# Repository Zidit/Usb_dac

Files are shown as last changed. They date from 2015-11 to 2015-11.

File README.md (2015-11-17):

USB DAC
=======
Basic external sound card based on Texas Instrument's PCM2706 USB DAC. The sound card has build in headphone amplifier based on NwAvGuy's [O2](http://nwavguy.blogspot.fi/2011/08/o2-details.html) design. It also has two line outputs and optical s/pdif output. All line and headphone outputs have individual volume control on front.
The amplifier needs external power supply to work. Power supply must provide 12 V to 16 V AC and at least 200 mA of current. There is also option to skip all amplification circuitry and drive headphone output directly from PCM2706. This way you don't need external power, but you lose line outputs and volume control.

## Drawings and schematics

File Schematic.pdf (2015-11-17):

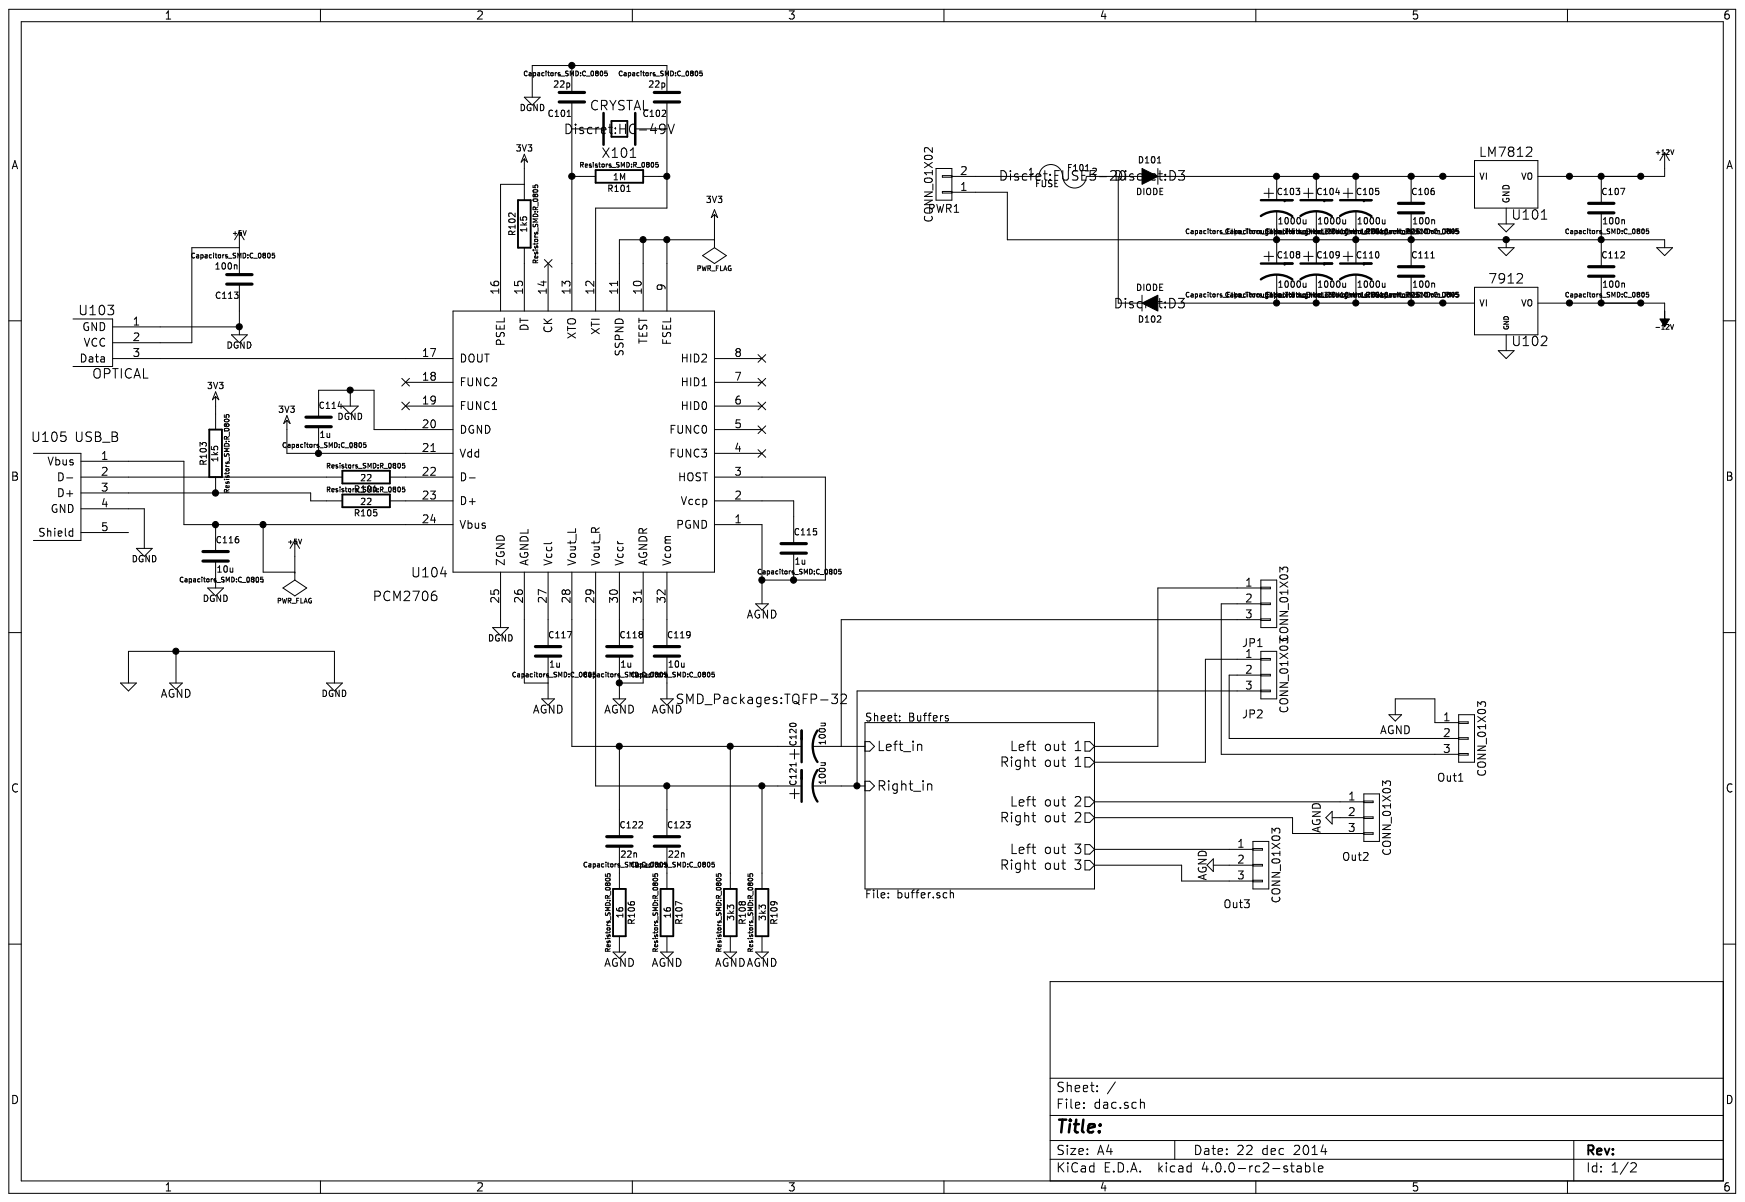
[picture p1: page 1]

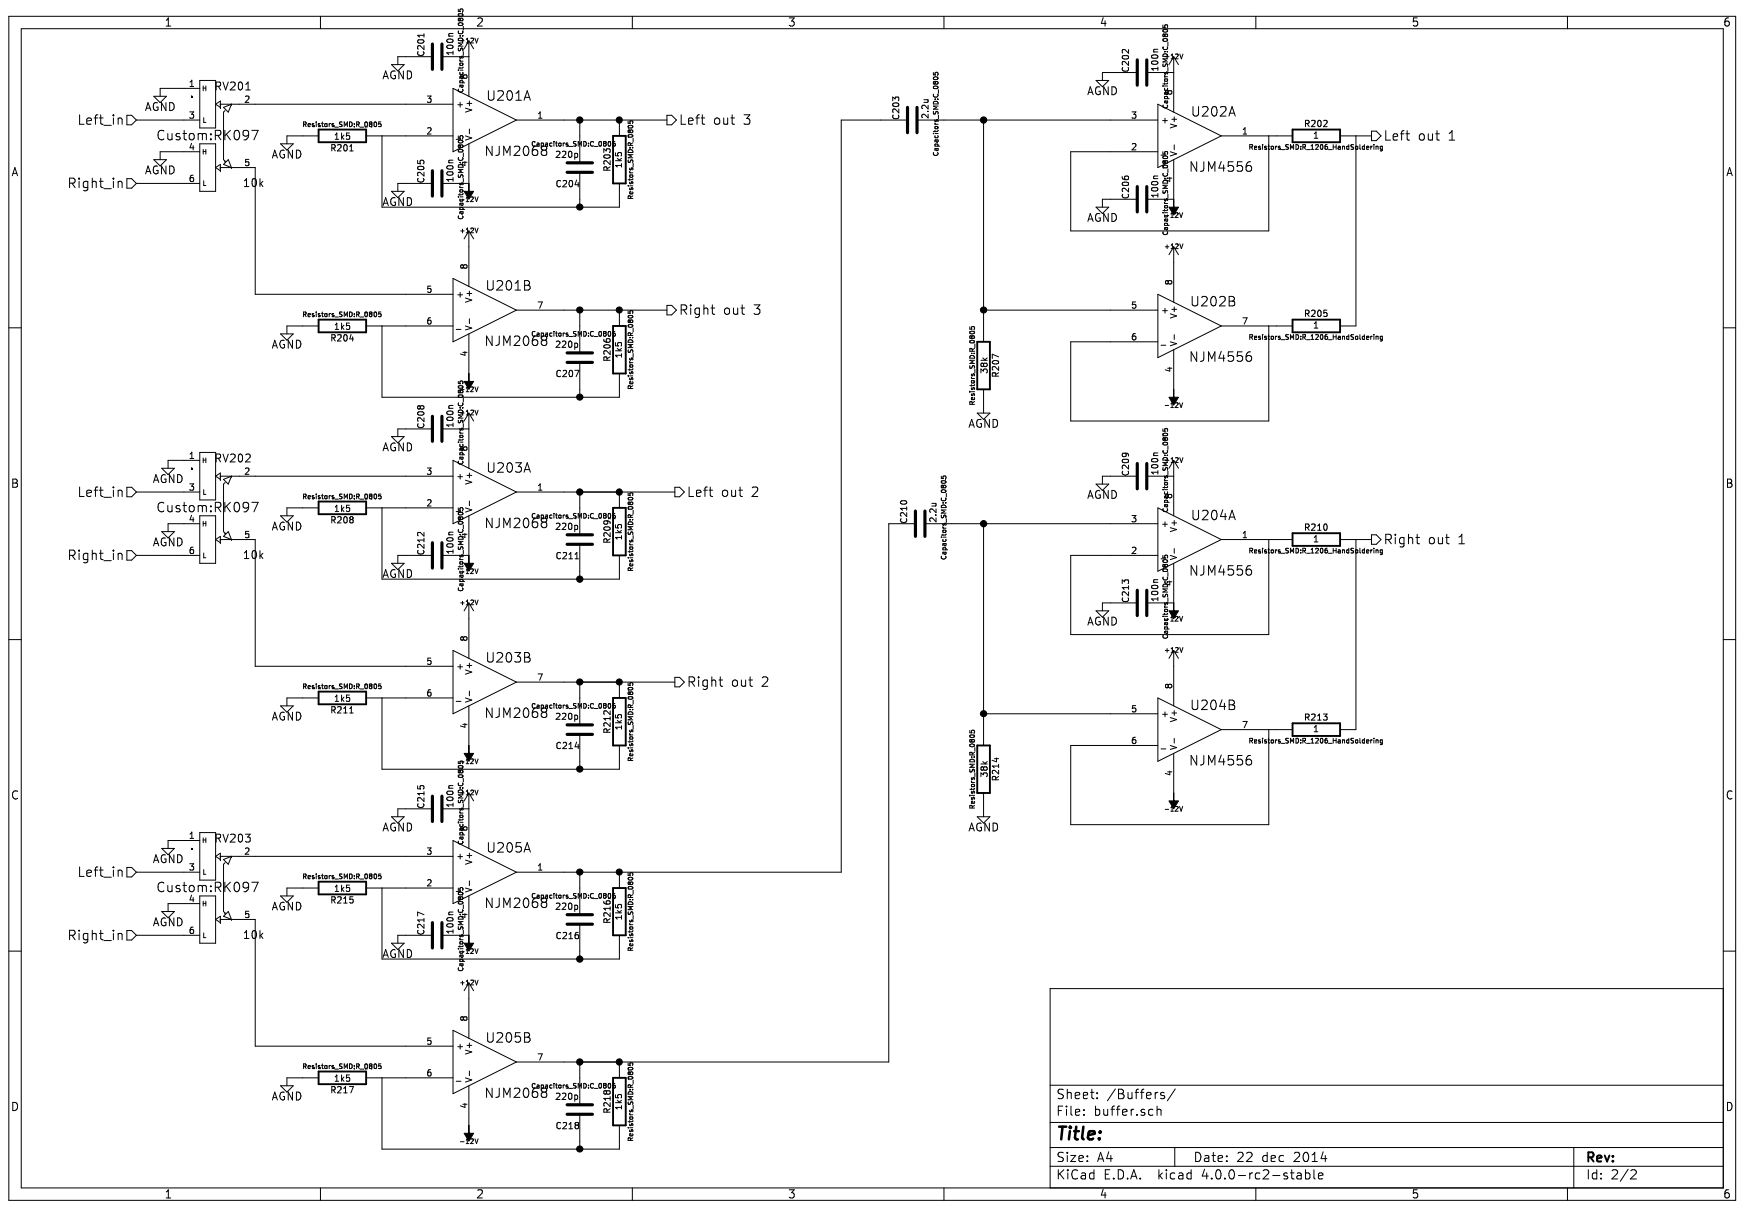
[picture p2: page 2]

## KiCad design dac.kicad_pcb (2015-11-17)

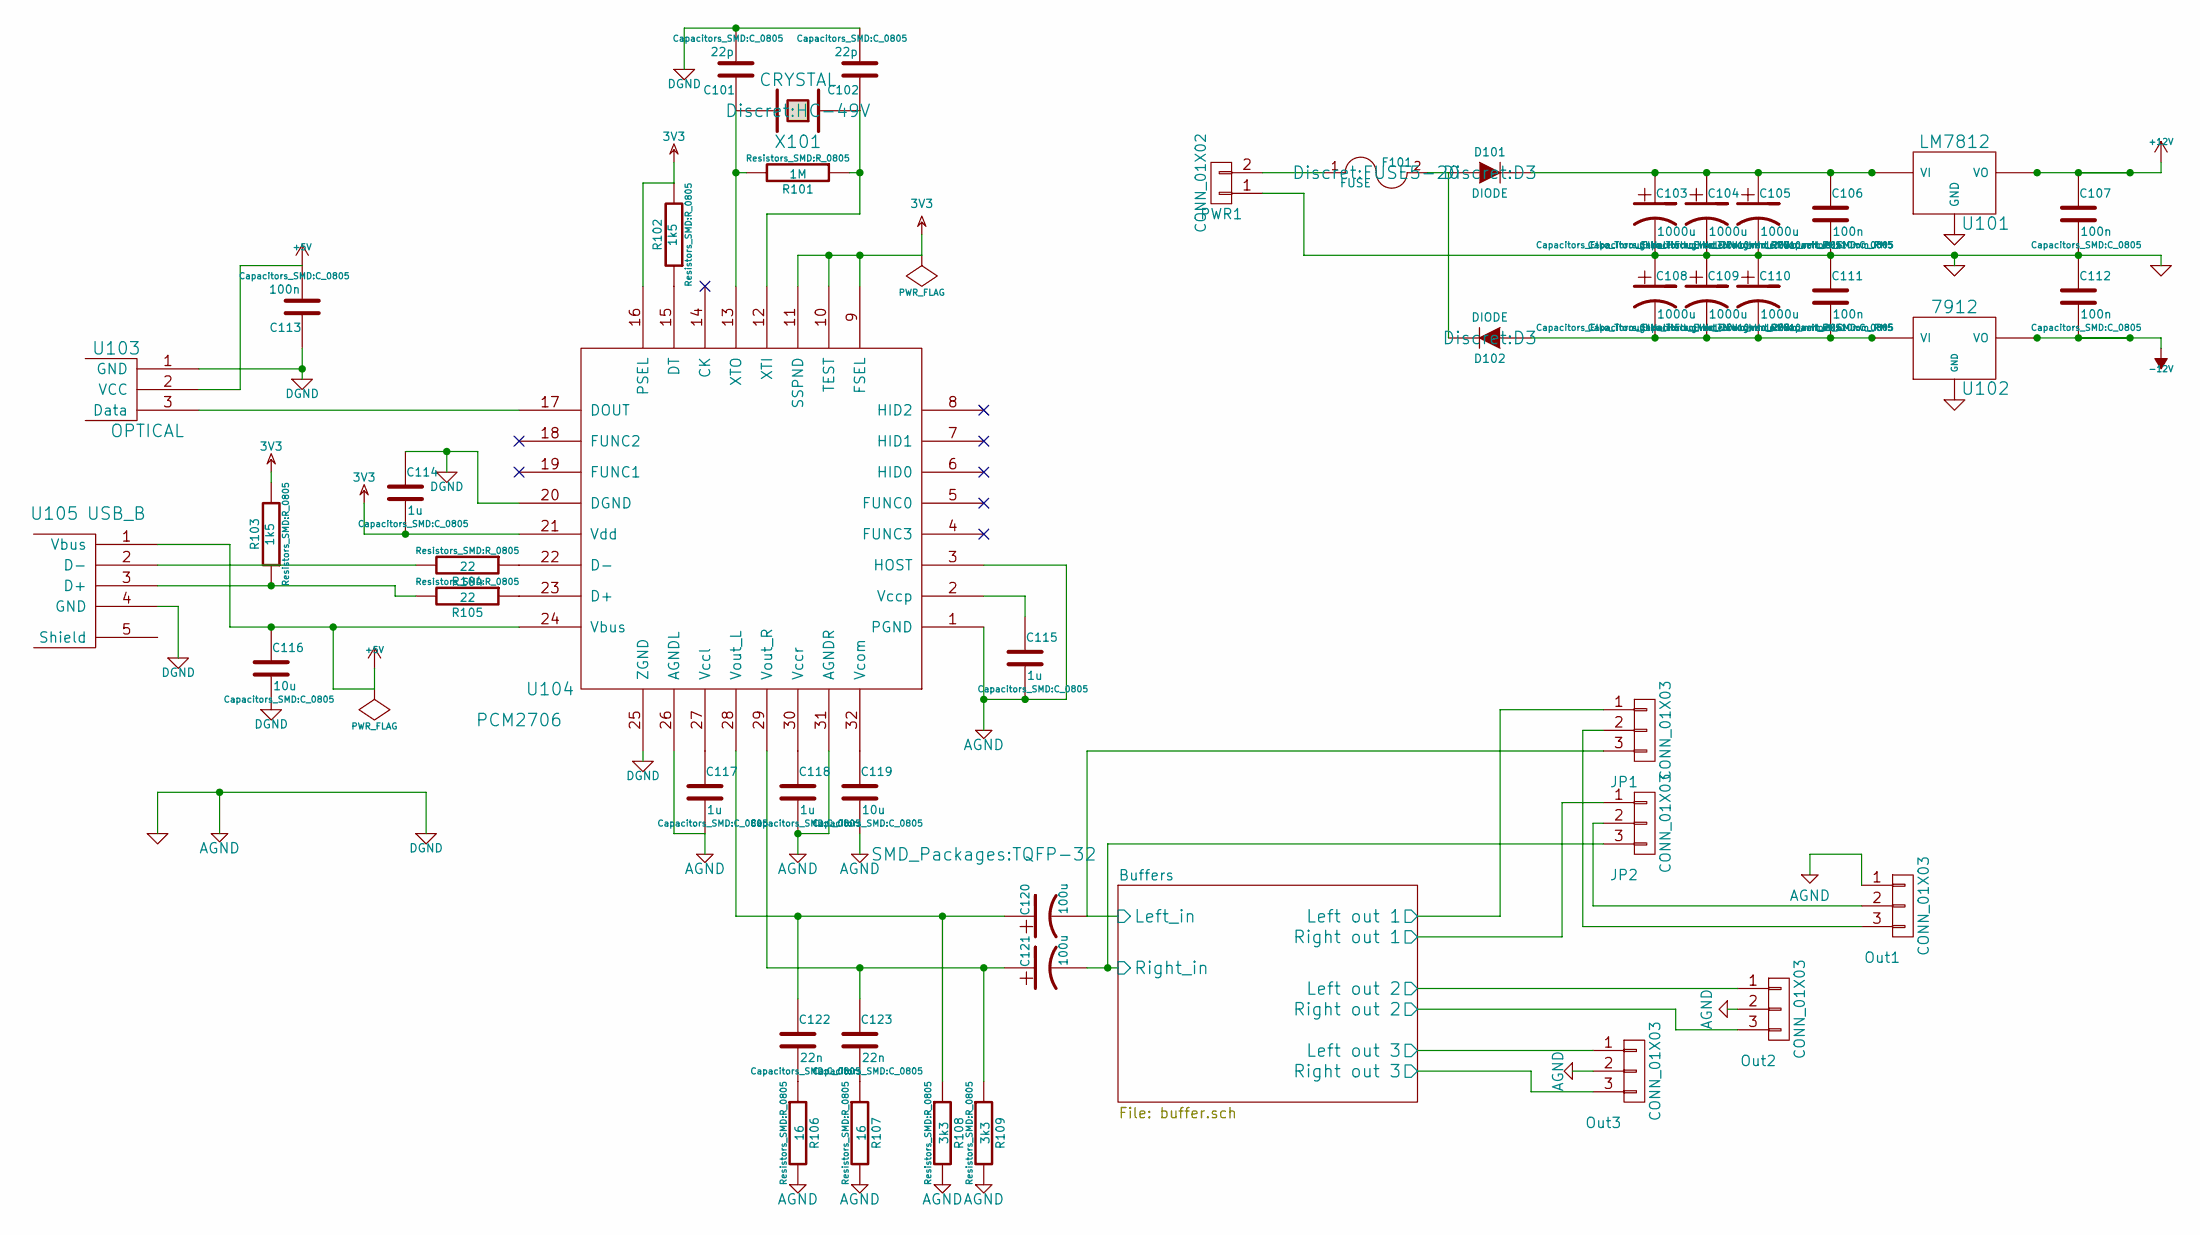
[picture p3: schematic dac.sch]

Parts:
C101, C102: 22p; C_0805
C103, C104, C105, C108, C109, C110: 1000u; Elko_vert_20x10mm_RM5
C106, C107, C111, C112, C113: 100n; C_0805
C114, C115, C117, C118: 1u; C_0805
C116, C119: 10u; C_0805
C120, C121: 100u; c_elec_6.3x5.3
C122, C123: 22n; C_0805
D101, D102: DIODE; D3
F101: FUSE; FUSE5-20
JP1, JP2: CONN_01X03; Pin_Header_Straight_1x03
Out1: CONN_01X03; SIKA
Out2, Out3: CONN_01X03; Pin_Header_Straight_1x03
PWR1: CONN_01X02; Pin_Header_Straight_1x02
R101: 1M; R_0805
R102, R103: 1k5; R_0805
R104, R105: 22; R_0805
R106, R107: 16; R_0805
R108, R109: 3k3; R_0805
U101: LM7812; TO220
U102: 7912; TO220
U103: OPTICAL; KFOX
U104: PCM2706; TQFP-32
U105: USB_B
X101: CRYSTAL; HC-49V

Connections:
3V3: C114.2, R102.2, R103.2, U104.9 (FSEL), U104.10 (TEST), U104.11 (SSPND), U104.16 (PSEL), U104.21 (Vdd)
+5V: C113.2, C116.1, U103.2 (VCC), U104.24 (Vbus), U105.1 (Vbus)
+12V: C107.1, U101.3 (VO); also elsewhere on the board
-12V: C112.2, U102.3 (VO); also elsewhere on the board
/Buffers/Left out 1: JP1.1; also elsewhere on the board
/Buffers/Left out 2: Out2.1; also elsewhere on the board
/Buffers/Left out 3: Out3.1; also elsewhere on the board
/Buffers/Left_in: C120.2, JP1.3; also elsewhere on the board
/Buffers/Right out 1: JP2.1; also elsewhere on the board
/Buffers/Right out 2: Out2.3; also elsewhere on the board
/Buffers/Right out 3: Out3.3; also elsewhere on the board
/Buffers/Right_in: C121.2, JP2.3; also elsewhere on the board
AGND: C101.2, C102.2, C103.2, C104.2, C105.2, C106.2, C107.2, C108.1, C109.1, C110.1, C111.1, C112.1, C113.1, C114.1, C115.2, C116.2, C117.2, C118.2, C119.2, Out1.1, Out2.2, Out3.2, PWR1.1, R106.2, R107.2, R108.2, R109.2, U101.2 (GND), U102.1 (GND), U103.1 (GND), U104.1 (PGND), U104.3 (HOST), U104.20 (DGND), U104.25 (ZGND), U104.26 (AGNDL), U104.31 (AGNDR), U105.4 (GND); also elsewhere on the board
unnamed: C101.1, R101.2, U104.13 (XTO), X101.2
unnamed: C102.1, R101.1, U104.12 (XTI), X101.1
unnamed: C103.1, C104.1, C105.1, C106.1, D101.2 (K), U101.1 (VI)
unnamed: C108.2, C109.2, C110.2, C111.2, D102.1 (A), U102.2 (VI)
unnamed: C115.1, U104.2 (Vccp)
unnamed: C117.1, U104.27 (Vccl)
unnamed: C118.1, U104.30 (Vccr)
unnamed: C119.1, U104.32 (Vcom)
unnamed: C120.1, C122.1, R108.1, U104.28 (Vout_L)
unnamed: C121.1, C123.1, R109.1, U104.29 (Vout_R)
unnamed: C122.2, R106.1
unnamed: C123.2, R107.1
unnamed: D101.1 (A), D102.2 (K), F101.2
unnamed: F101.1, PWR1.2
unnamed: JP1.2, Out1.3
unnamed: JP2.2, Out1.2
unnamed: R102.1, U104.15 (DT)
unnamed: R103.1, R105.2, U105.3 (D+)
unnamed: R104.1, U104.22 (D-)
unnamed: R104.2, U105.2 (D-)
unnamed: R105.1, U104.23 (D+)
unnamed: U103.3 (Data), U104.17 (DOUT)

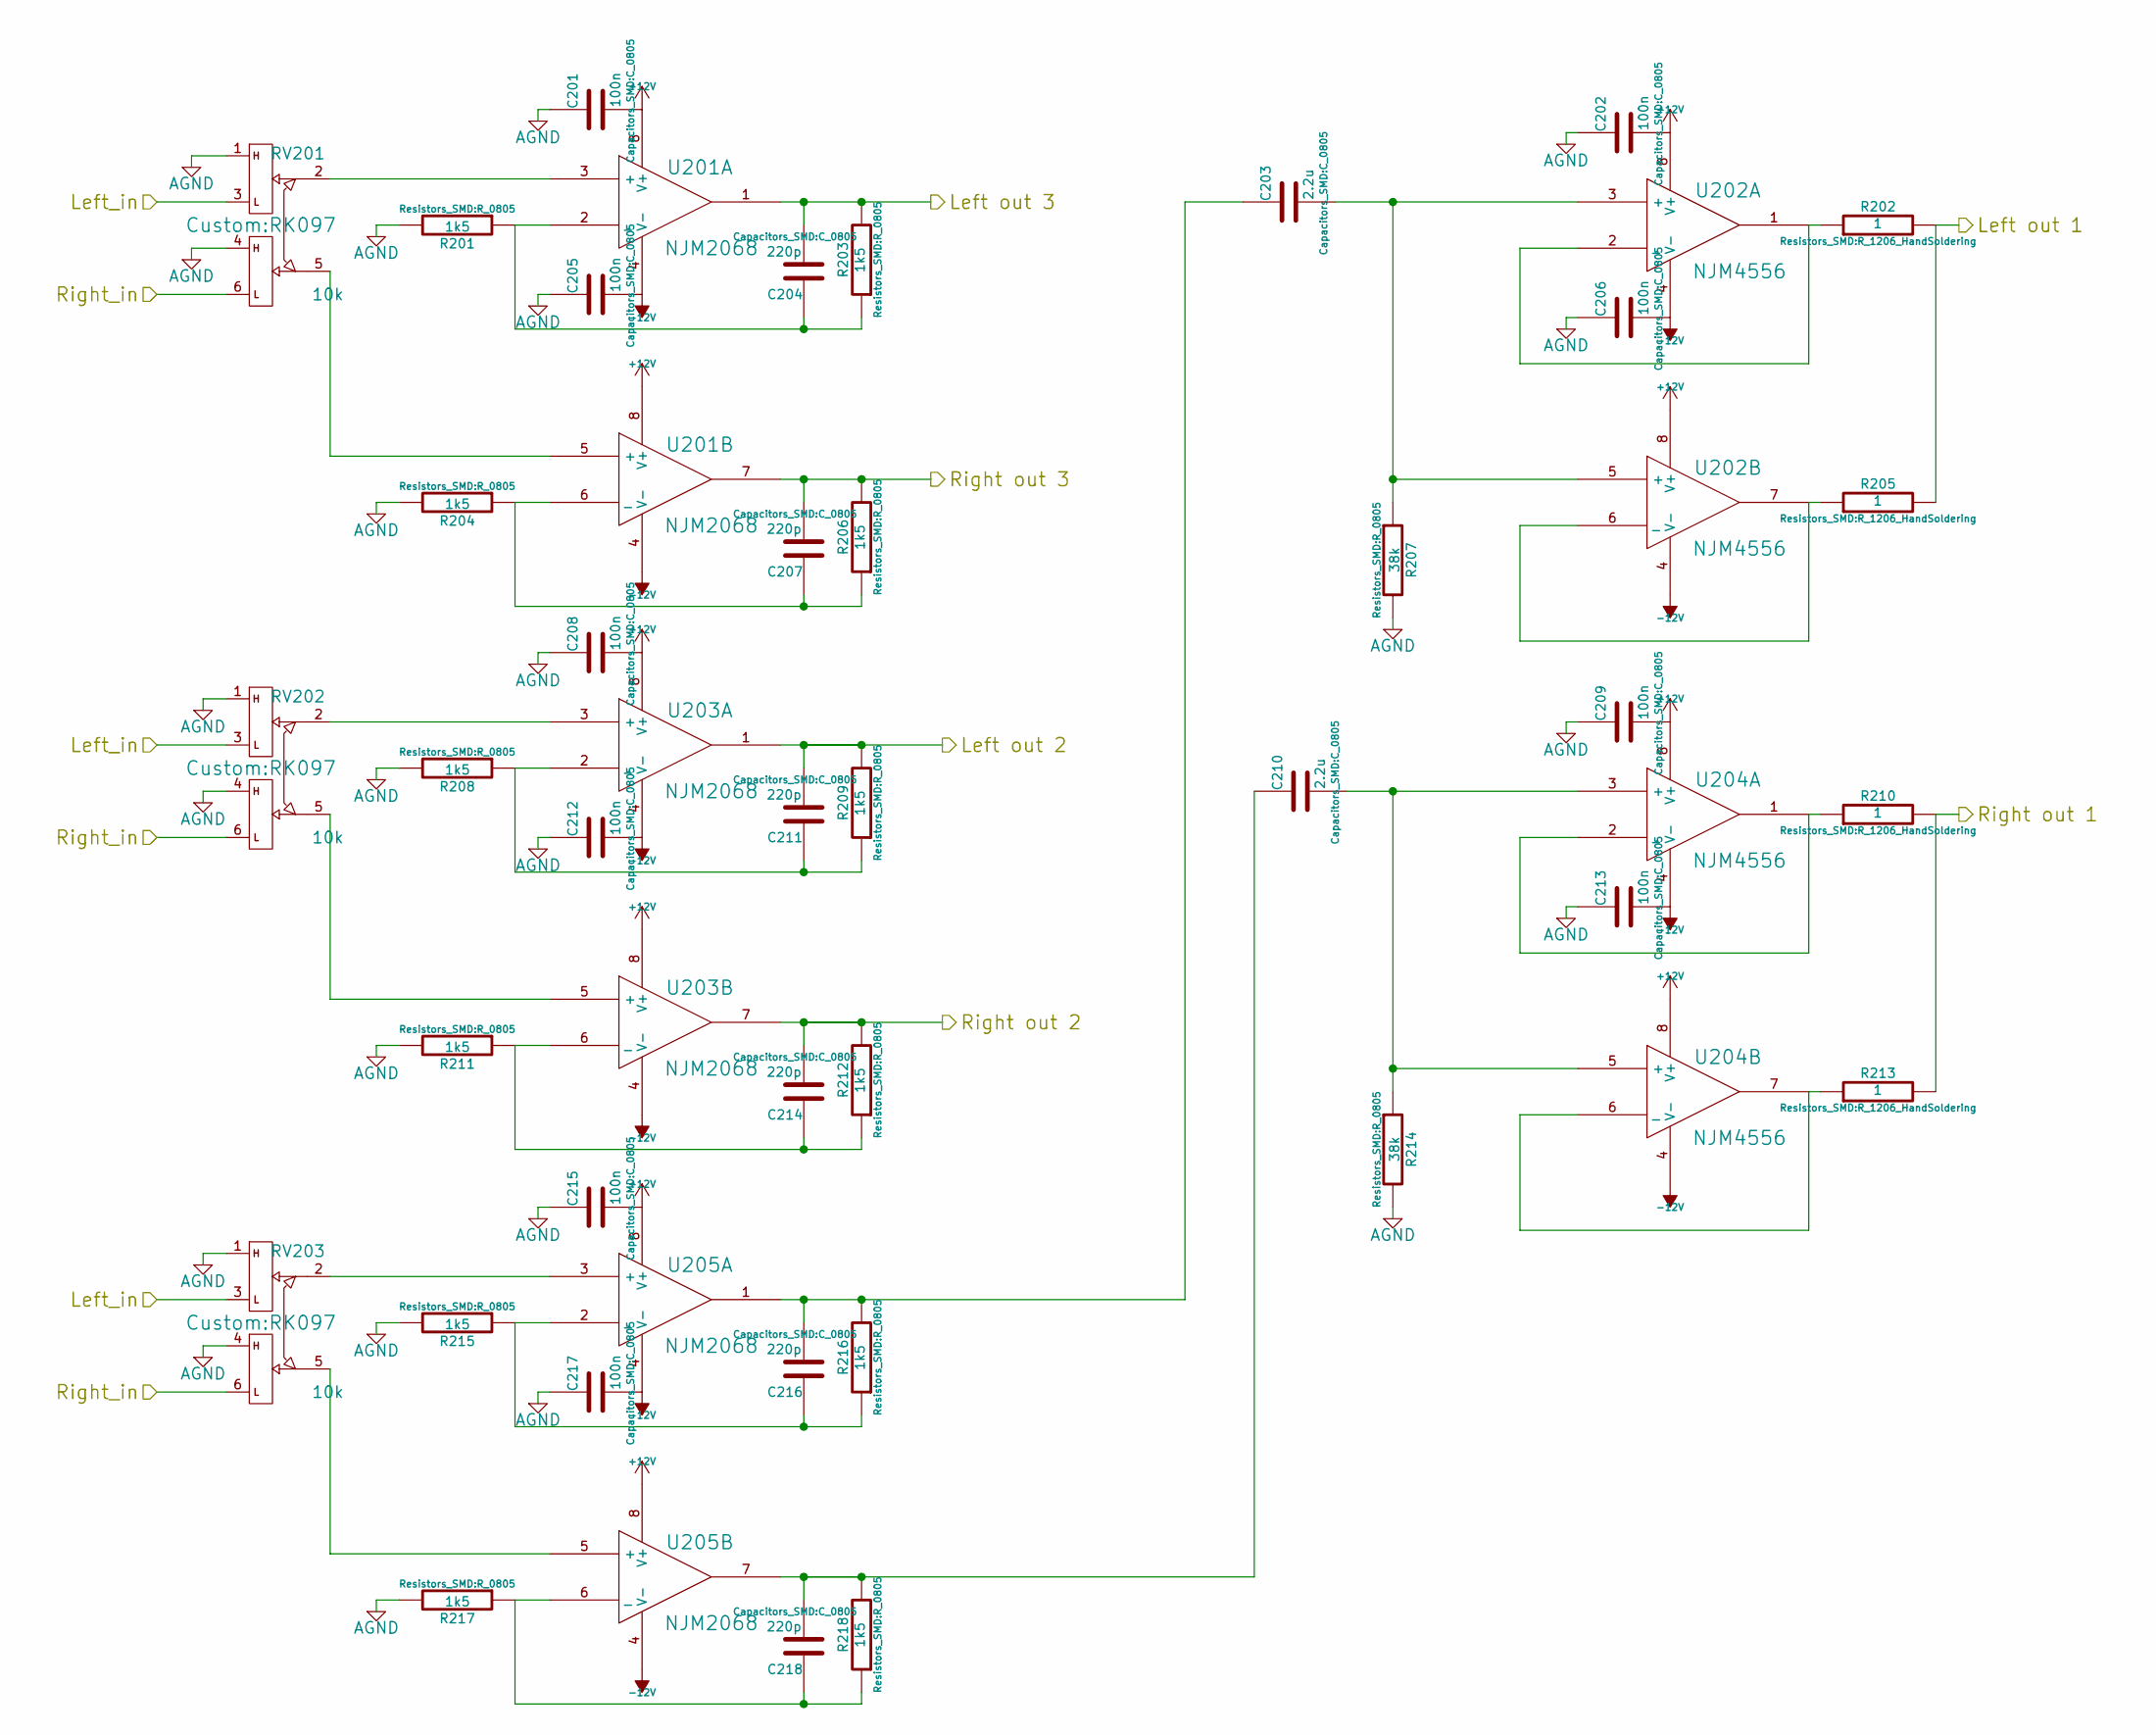
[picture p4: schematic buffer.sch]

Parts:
C201, C202, C205, C206, C208, C209, C212, C213, C215, C217: 100n; C_0805
C203, C210: 2.2u; C_0805
C204, C207, C211, C214, C216, C218: 220p; C_0805
R201, R203, R204, R206, R208, R209, R211, R212, R215, R216, R217, R218: 1k5; R_0805
R202, R205, R210, R213: 1; R_1206_HandSoldering
R207, R214: 38k; R_0805
RV201, RV202, RV203: 10k; RK097
U201, U203, U205: NJM2068; SOIC 8
U202, U204: NJM4556; SOIC 8

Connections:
+12V: C201.2, C202.2, C208.2, C209.2, C215.2, U201.8 (V+), U202.8 (V+), U203.8 (V+), U204.8 (V+), U205.8 (V+); also elsewhere on the board
-12V: C205.2, C206.2, C212.2, C213.2, C217.2, U201.4 (V-), U202.4 (V-), U203.4 (V-), U204.4 (V-), U205.4 (V-); also elsewhere on the board
/Buffers/Left out 1: R202.2, R205.2; also elsewhere on the board
/Buffers/Left out 2: C211.2, R209.2, U203.1; also elsewhere on the board
/Buffers/Left out 3: C204.2, R203.2, U201.1; also elsewhere on the board
/Buffers/Left_in: RV201.3, RV202.3, RV203.3; also elsewhere on the board
/Buffers/Right out 1: R210.2, R213.2; also elsewhere on the board
/Buffers/Right out 2: C214.2, R212.2, U203.7; also elsewhere on the board
/Buffers/Right out 3: C207.2, R206.2, U201.7; also elsewhere on the board
/Buffers/Right_in: RV201.6, RV202.6, RV203.6; also elsewhere on the board
AGND: C201.1, C202.1, C205.1, C206.1, C208.1, C209.1, C212.1, C213.1, C215.1, C217.1, R201.2, R204.2, R207.2, R208.2, R211.2, R214.2, R215.2, R217.2, RV201.1, RV201.4, RV202.1, RV202.4, RV203.1, RV203.4; also elsewhere on the board
unnamed: C203.1, C216.2, R216.2, U205.1
unnamed: C203.2, R207.1, U202.3 (+), U202.5 (+)
unnamed: C204.1, R201.1, R203.1, U201.2 (_)
unnamed: C207.1, R204.1, R206.1, U201.6 (_)
unnamed: C210.1, C218.2, R218.2, U205.7
unnamed: C210.2, R214.1, U204.3 (+), U204.5 (+)
unnamed: C211.1, R208.1, R209.1, U203.2 (_)
unnamed: C214.1, R211.1, R212.1, U203.6 (_)
unnamed: C216.1, R215.1, R216.1, U205.2 (_)
unnamed: C218.1, R217.1, R218.1, U205.6 (_)
unnamed: R202.1, U202.1, U202.2 (_)
unnamed: R205.1, U202.6 (_), U202.7
unnamed: R210.1, U204.1, U204.2 (_)
unnamed: R213.1, U204.6 (_), U204.7
unnamed: RV201.2, U201.3 (+)
unnamed: RV201.5, U201.5 (+)
unnamed: RV202.2, U203.3 (+)
unnamed: RV202.5, U203.5 (+)
unnamed: RV203.2, U205.3 (+)
unnamed: RV203.5, U205.5 (+)

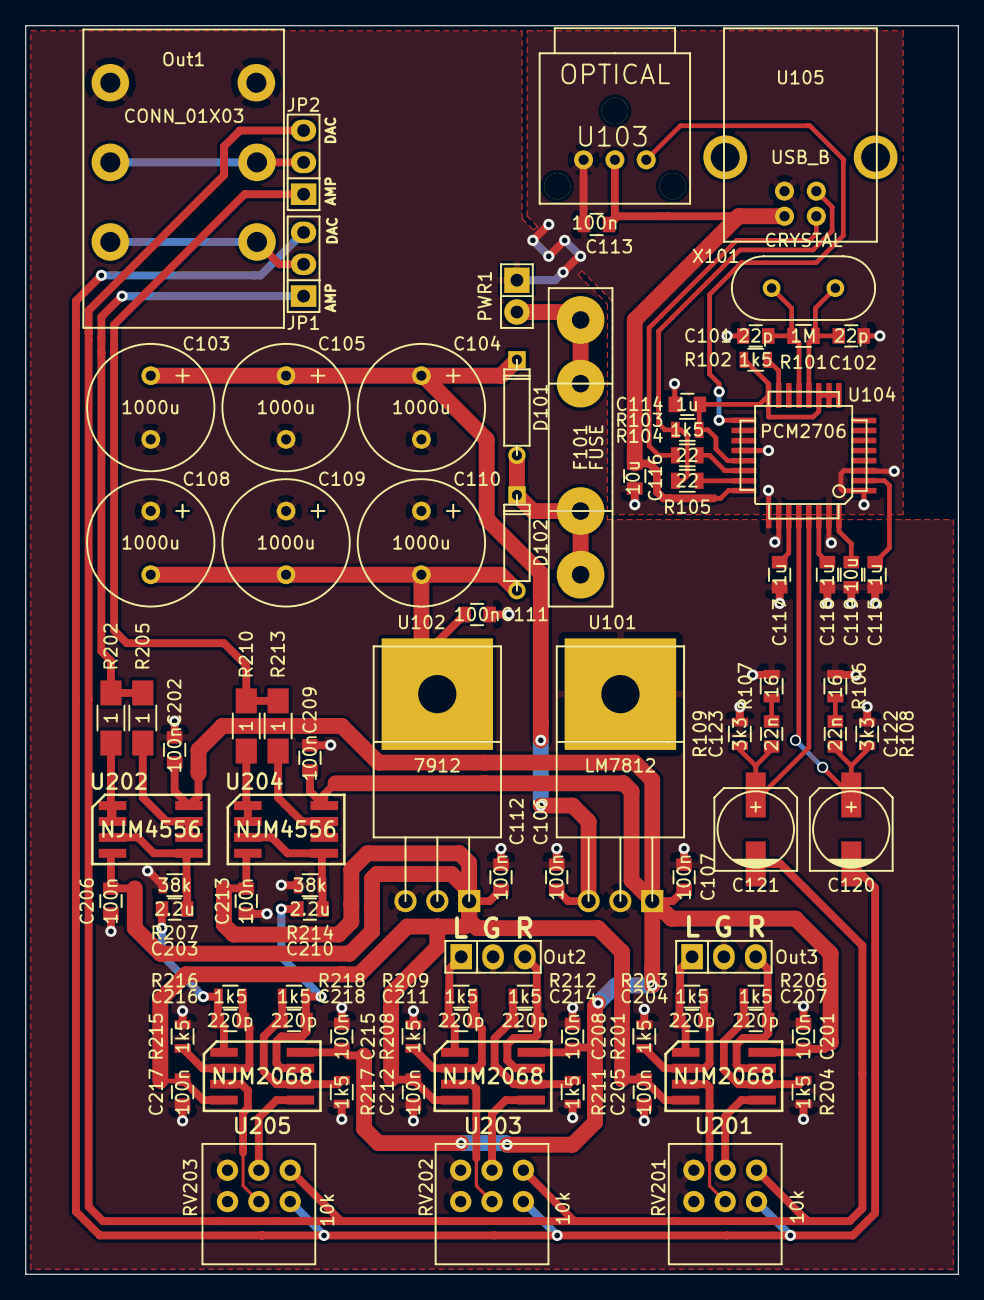
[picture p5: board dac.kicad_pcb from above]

Board: 2 copper layers, 74.4 x 99.6 mm, 91 parts (0 on the bottom side), 55 nets.
